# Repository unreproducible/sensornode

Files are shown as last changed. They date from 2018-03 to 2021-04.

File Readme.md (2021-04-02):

# SensorNode - Development Board

This is a board mostly intended to make a high quality environmental sensor
(BME280 or BME680) available via the magic of "IoT".  The board has some
interesting features that should make it good for training, teaching, or just
general IoT uses:
* ESP32
    * Wifi
    * Bluetooth
    * 4MB Flash
* BME280 / BME680 Support
  * Temperature
  * Pressure 
  * Humidity
* TSL2591
    * Full Spectrum Light Sensor
    * IR Spectrum Light Sensor
* MicroSD card slot
* LiPo battery support (charging and discharging)
* CP2104 USB <-> Serial Port
* Working Good Display E-ink support (specifically 2.13in screens)
    * v1.2 or later

# Getting Started
The following link is a presentation that was done in 2018 specifically targetting this board

https://events.linuxfoundation.org/wp-content/uploads/2017/12/osseu18_-_discovering_tiny_snakes_John-Hawley.pdf

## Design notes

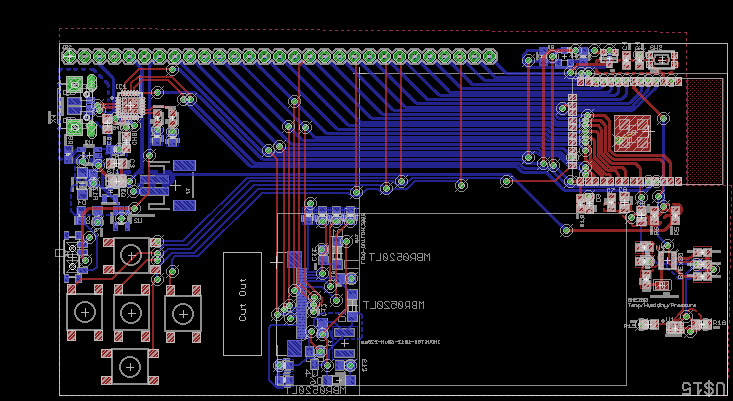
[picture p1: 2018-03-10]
Board Image - sensornode.png

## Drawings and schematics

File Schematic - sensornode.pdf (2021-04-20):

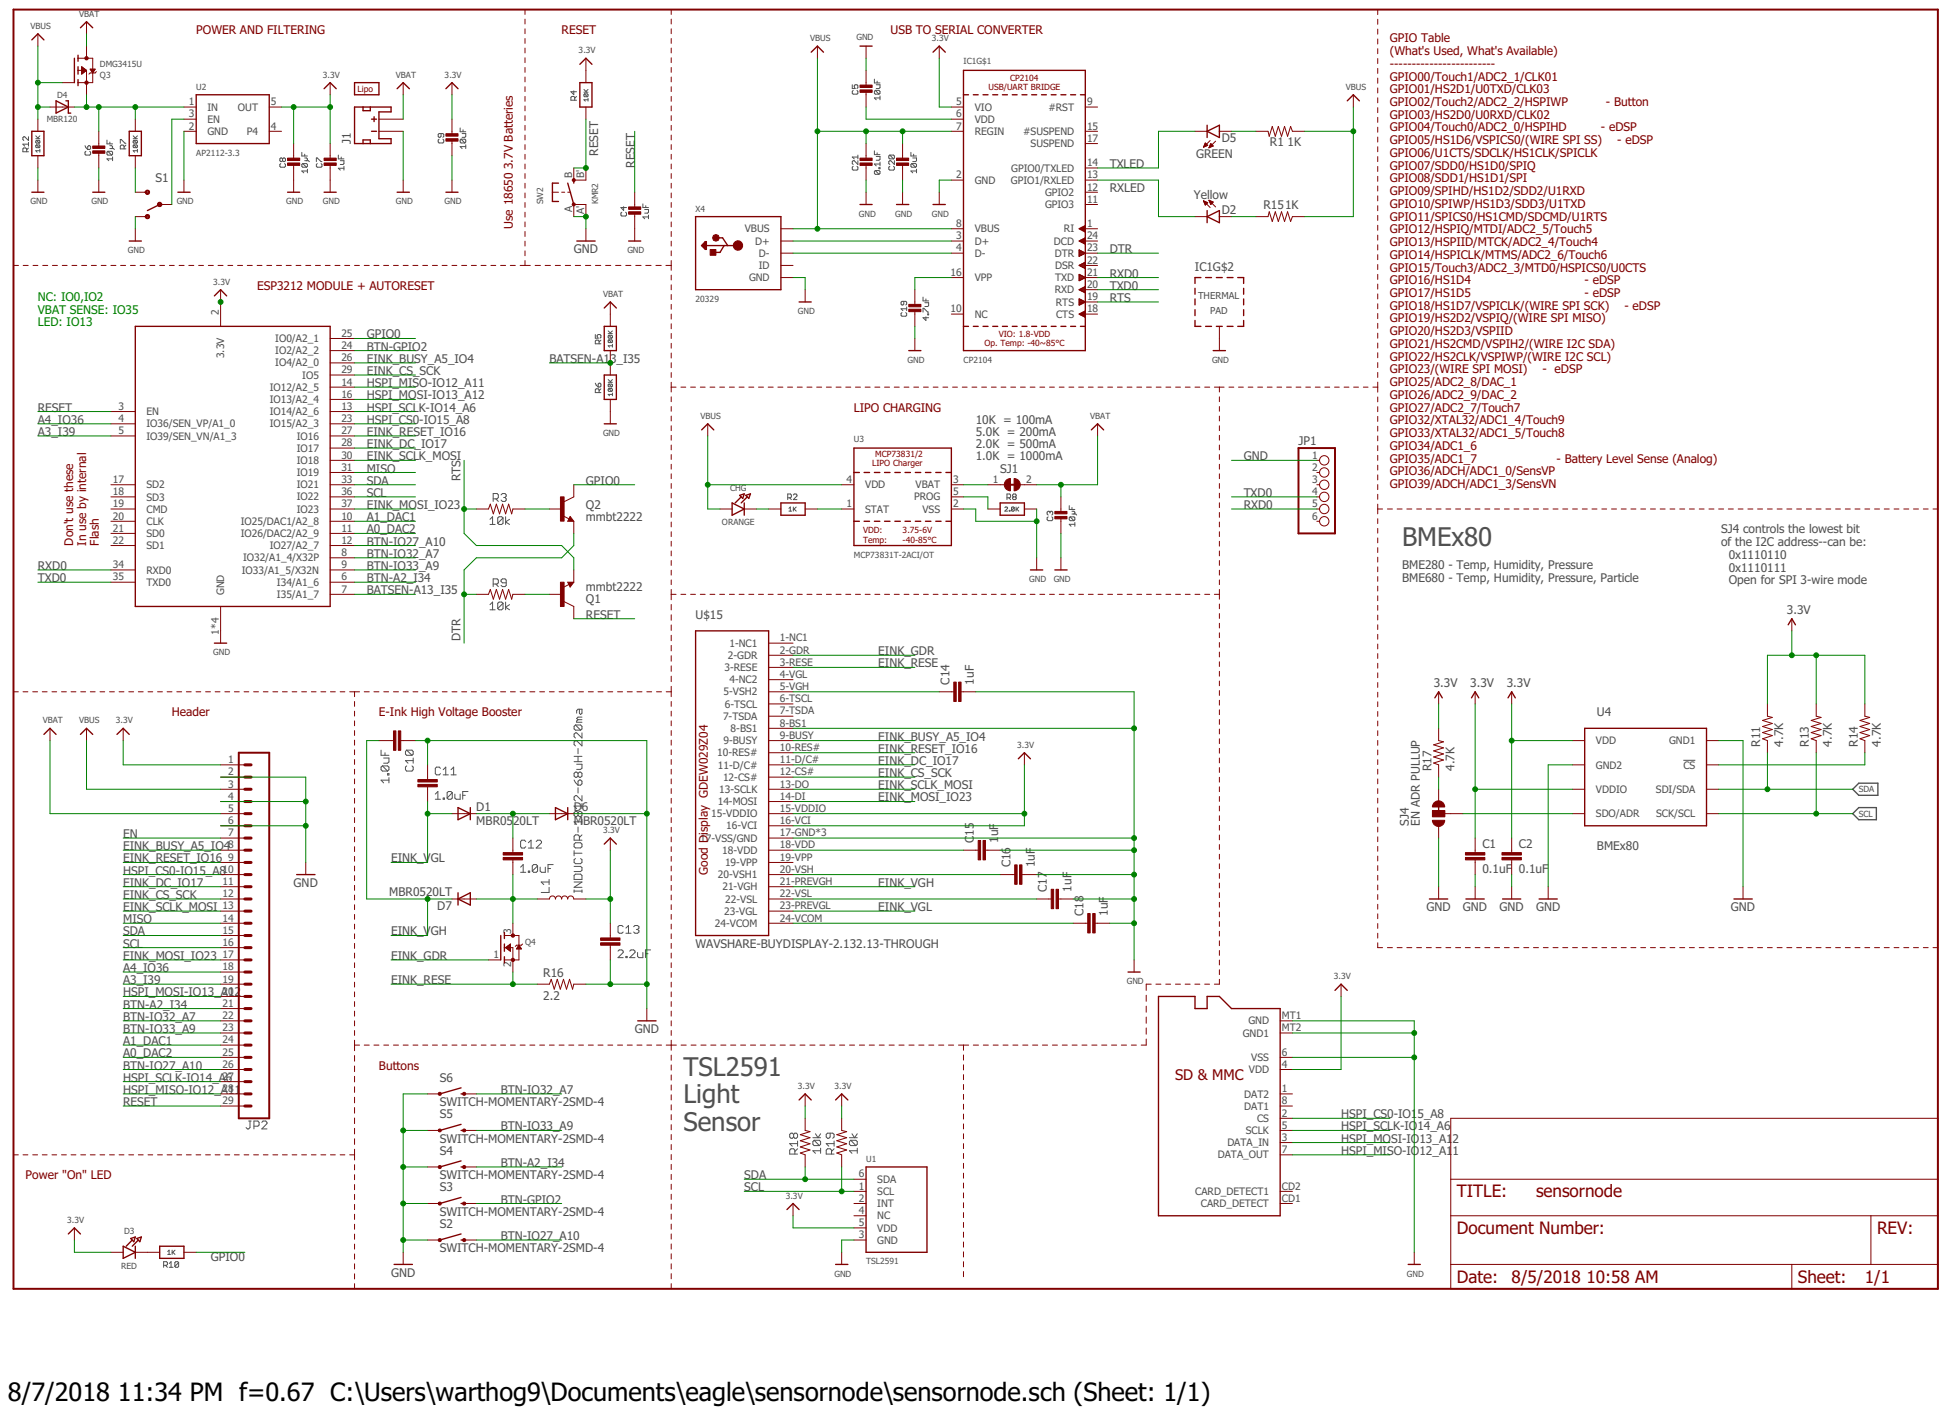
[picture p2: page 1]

GPIO Table
(What's Used, What's Available)

VIO: 1.8-VDD Op. Temp: -40~85°C

In use by internal Flash

SJ4 controls the lowest bit of the I2C address--can be: 0x1110110

0x1110111 Open for SPI 3-wire mode BME280 - Temp, Humidity, Pressure BME680 - Temp, Humidity, Pressure, Particle

E-Ink High Voltage Booster

SWITCH-MOMENTARY-2SMD-4 SWITCH-MOMENTARY-2SMD-4 SWITCH-MOMENTARY-2SMD-4

REV: TITLE: Document Number: sensornode

SWITCH-MOMENTARY-2SMD-4

8/7/2018 11:34 PM f=0.67 C:\Users\warthog9\Documents\eagle\sensornode\sensornode.sch (Sheet: 1/1)

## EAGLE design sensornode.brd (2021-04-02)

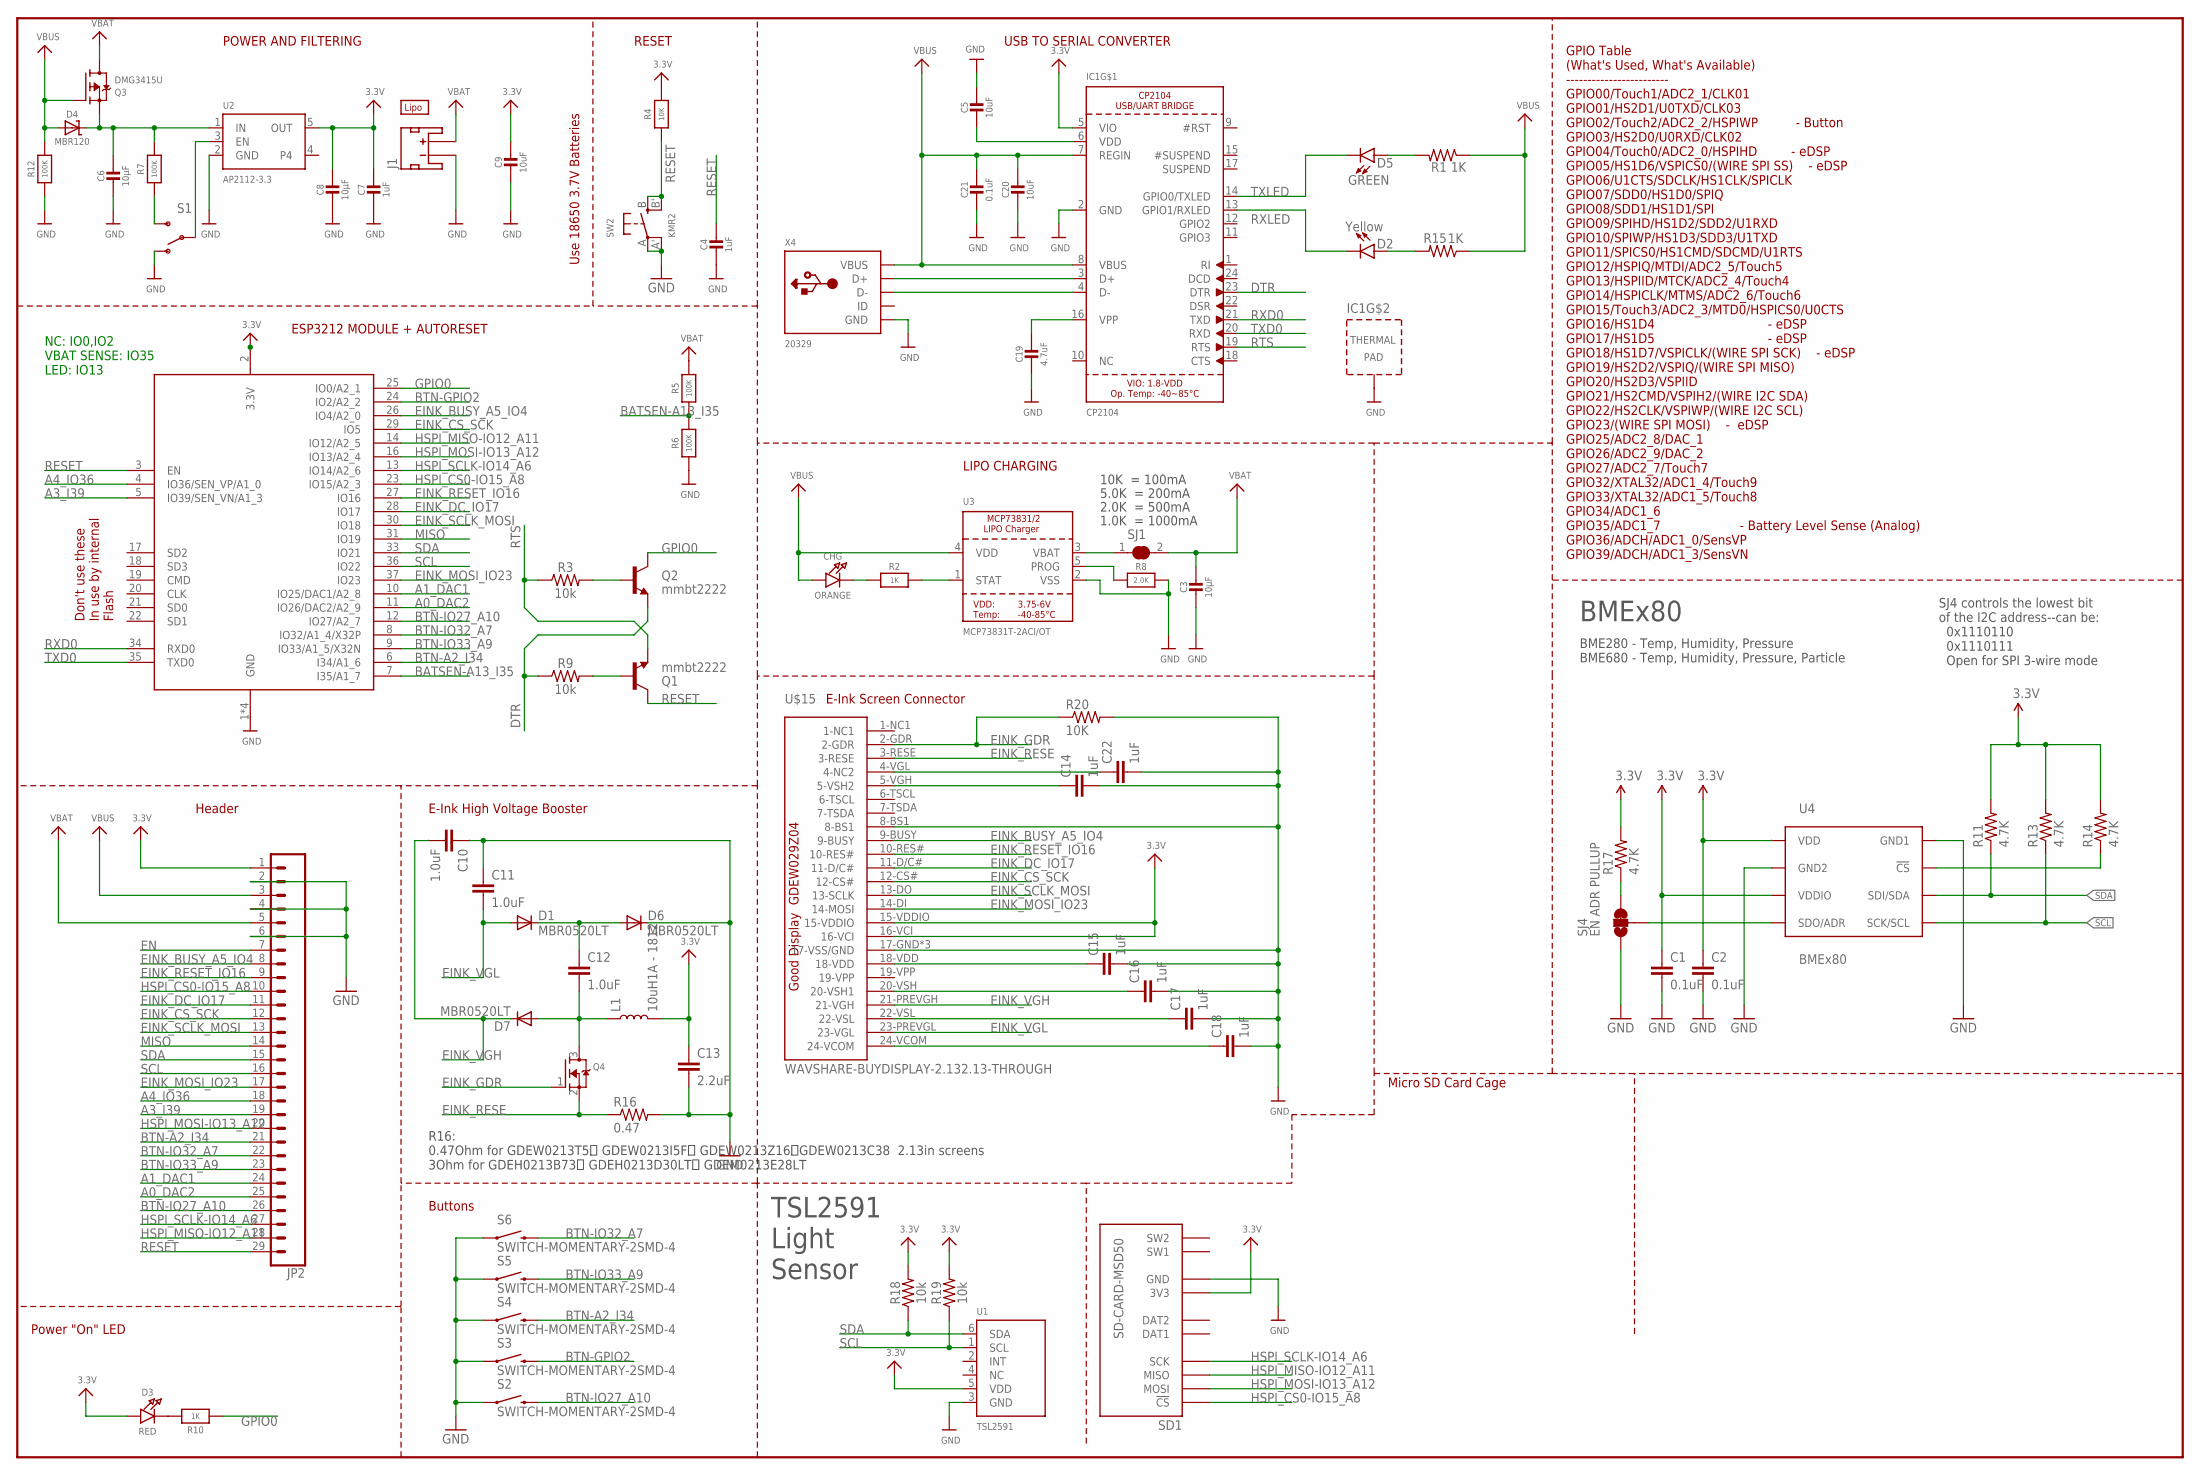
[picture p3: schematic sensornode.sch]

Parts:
BT1: LIPO-OUTLINE2000; LIPO-2000
C1, C2: 0.1uF; 0603-CAP
C3, C6, C8: 10µF; 0805-NO
C4, C7: 1uF; 0603-NO
C5, C9, C20: 10uF; 0805-NO
C10, C11, C12: 1.0uF; 0603
C13: 2.2uF; 0603
C14, C15, C16, C17, C18, C22: 1uF; 0603-CAP
C19: 4.7uF; 0805-NO
C21: 0.1uF; 0805-NO
CHG: ORANGE; CHIPLED_0805_NOOUTLINE
D1, D6, D7: MBR0520LT; SOD123
D2: Yellow; LED-0603
D3: RED; CHIPLED_0805_NOOUTLINE
D4: MBR120; SOD-123
D5: GREEN; LED-0603
IC1: CP2104; QFN24_4MM_SMSC
J1: JST_2MM_MALE; JST-2-SMD
JP2: CONN_29; 1X29
L1: 10uH1A - 1812; 1815
Q1, Q2: mmbt2222; SOT23-3
Q3: DMG3415U; SOT23-R
Q4: MOSFET-NREFLOW; SOT23
R1, R15: 1K; 0603-RES
R2, R10: 1K; 0603-NO
R3, R9, R18, R19: 10k; 0603
R4: 10K; 0603-NO
R5, R6, R7, R12: 100K; 0603-NO
R8: 2.0K; 0603-NO
R11, R13, R14, R17: 4.7K; 0603-RES
R16: 0.47; 0603-RES
R20: 10K; 0603-RES
S1: SWITCH-SPDT-SMD-A; SWITCH-SPST-SMD-A
S2, S3, S4, S5, S6: SWITCH-MOMENTARY-2SMD-4; TACTILE_SWITCH_TALL
SD1: SD-CARD-MSD50; SD_5031821853
SJ1: SOLDERJUMPER_CLOSED; SOLDERJUMPER_CLOSEDWIRE@1
SJ4: EN ADR PULLUP; PAD-JUMPER-3-2OF3_NC_BY_TRACE_YES_SILK_FULL_BOX
SW2: KMR2; BTN_KMR2_4.6X2.8
U1: TSL2591; DFN6_TAOS
U2: AP2112-3.3; SOT23-5
U3: MCP73831T-2ACI/OT; SOT23-5
U4: BMEx80; BME280_LGA
U$15: WAVSHARE-BUYDISPLAY-2.132.13-THROUGH; WAVSHARE-BUYDISPLAY-2.13-THM
X2: ESP32_WROOM32_SKINNY; WROOM32_SKINNY
X4: 20329; MICRO-USB5+6P-SMD-0.65-B

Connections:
3.3V: C1.1, C2.1, C7.1, C8.1, C9.1, C13.1, D3.A, IC1.5 (VIO), JP2.1, L1.2, R1.1, R4.2, R11.2, R13.2, R14.2, R15.1, R17.2, R18.2, R19.2, SD1.VCC (3V3), U1.5 (VDD), U2.5 (OUT), U4.P$6 (VDDIO), U4.P$8 (VDD), U$15.15-VDDIO, U$15.16-VCI, X2.2 (3.3V)
!CS: R14.1, U4.P$2 (!CS)
A0_DAC2: JP2.25, X2.11 (IO26/DAC2/A2_9)
A1_DAC1: JP2.24, X2.10 (IO25/DAC1/A2_8)
A3_I39: JP2.19, X2.5 (IO39/SEN_VN/A1_3)
A4_IO36: JP2.18, X2.4 (IO36/SEN_VP/A1_0)
BATSEN-A13_I35: R5.1, R6.2, X2.7 (I35/A1_7)
BTN-A2_I34: JP2.21, S4.B2 (2), X2.6 (I34/A1_6)
BTN-GPIO2: S3.B2 (2), X2.24 (IO2/A2_2)
BTN-IO27_A10: JP2.26, S2.B2 (2), X2.12 (IO27/A2_7)
BTN-IO32_A7: JP2.22, S6.B2 (2), X2.8 (IO32/A1_4/X32P)
BTN-IO33_A9: JP2.23, S5.B2 (2), X2.9 (IO33/A1_5/X32N)
DTR: IC1.23 (DTR), Q2.2 (E), R9.1
EINK_BUSY_A5_IO4: JP2.8, U$15.9-BUSY, X2.26 (IO4/A2_0)
EINK_CS_SCK: JP2.12, U$15.12-CS#, X2.29 (IO5)
EINK_DC_IO17: JP2.11, U$15.11-D/C#, X2.28 (IO17)
EINK_GDR: Q4.1 (G), R20.1, U$15.2-GDR
EINK_MOSI_IO23: JP2.17, U$15.14-DI (14-MOSI), X2.37 (IO23)
EINK_RESE: Q4.2 (S), R16.1, U$15.3-RESE
EINK_RESET_IO16: JP2.9, U$15.10-RES#, X2.27 (IO16)
EINK_SCLK_MOSI: JP2.13, U$15.13-DO (13-SCLK), X2.30 (IO18)
EINK_VGH: C10.2, D7.C, U$15.21-PREVGH (21-VGH)
EINK_VGL: C11.2, D1.A, U$15.23-PREVGL (23-VGL)
EN: JP2.7, S1.2, U2.3 (EN)
GND: C1.2, C2.2, C3.2, C4.2, C5.1, C6.2, C7.2, C8.2, C9.2, C10.1, C11.1, C13.2, C14.2, C15.2, C16.2, C17.2, C18.2, C19.2, C20.2, C21.2, C22.2, D6.C, IC1.2 (GND), IC1.THERM (TP), J1.1 (-), JP2.2, JP2.4, JP2.6, R6.1, R8.2, R12.1, R16.2, R20.2, S1.1 (O), S2.A2 (1), S3.A2 (1), S4.A2 (1), S5.A2 (1), S6.A2 (1), SD1.GND, SJ4.1, SW2.A, SW2.A' (P1), U1.3 (GND), U2.2 (GND), U3.2 (VSS), U4.P$1 (GND1), U4.P$7 (GND2), U$15.8-BS1, U$15.17-GND (17-VSS/GND), U$15.25 (17-VSS/GND), U$15.26 (17-VSS/GND), X2.1 (GND), X2.15 (GND), X2.38 (GND), X2.P$1 (GND), X4.5 (GND), X4.S1 (GND), X4.S2 (GND), X4.S3 (GND), X4.S4 (GND), X4.S5 (GND), X4.S6 (GND)
GPIO0: Q2.3 (C), R10.1, X2.25 (IO0/A2_1)
HSPI_CS0-IO15_A8: JP2.10, SD1.CS (!CS), X2.23 (IO15/A2_3)
HSPI_MISO-IO12_A11: JP2.28, SD1.MISO, X2.14 (IO12/A2_5)
HSPI_MOSI-IO13_A12: JP2.20, SD1.MOSI, X2.16 (IO13/A2_4)
HSPI_SCLK-IO14_A6: JP2.27, SD1.SCK, X2.13 (IO14/A2_6)
MISO: JP2.14, X2.31 (IO19)
unnamed: CHG.C, R2.1
unnamed: R8.1, U3.5 (PROG)
unnamed: R2.2, U3.1 (STAT)
unnamed: R7.1, S1.3 (S)
unnamed: D3.C, R10.2
unnamed: C5.2, IC1.6 (VDD)
unnamed: C6.1, D4.C, Q3.2 (S), R7.2, U2.1 (IN)
unnamed: D5.A, R1.2
unnamed: SJ1.1, U3.3 (VBAT)
unnamed: D2.A, R15.2
unnamed: C12.1, D1.C, D6.A
unnamed: Q1.1 (B), R9.2
unnamed: Q2.1 (B), R3.2
unnamed: C12.2, D7.A, L1.1, Q4.3 (D)
unnamed: R17.1, SJ4.3
unnamed: C15.1, U$15.18-VDD
unnamed: C16.1, U$15.20-VSH (20-VSH1)
unnamed: C17.1, U$15.22-VSL
unnamed: C18.1, U$15.24-VCOM
unnamed: C14.1, U$15.5-VGH (5-VSH2)
unnamed: C19.1, IC1.16 (VPP)
unnamed: C22.1, U$15.4-VGL (4-NC2)
RESET: C4.1, JP2.29, Q1.3 (C), R4.1, SW2.B (S), SW2.B' (S1), X2.3 (EN)
RTS: IC1.19 (RTS), Q1.2 (E), R3.1
RXD0: IC1.21 (TXD), X2.34 (RXD0)
RXLED: D2.C, IC1.13 (GPIO1/RXLED)
SCL: JP2.16, R13.1, R19.1, U1.1 (SCL), U4.P$4 (SCK/SCL), X2.36 (IO22)
SDA: JP2.15, R11.1, R18.1, U1.6 (SDA), U4.P$3 (SDI/SDA), X2.33 (IO21)
SDO/ADR: SJ4.2, U4.P$5 (SDO/ADR)
TXD0: IC1.20 (RXD), X2.35 (TXD0)
TXLED: D5.C, IC1.14 (GPIO0/TXLED)
USBD_N: IC1.4 (D-), X4.2 (D-)
USBD_P: IC1.3 (D+), X4.3 (D+)
VBAT: C3.1, J1.2 (+), JP2.5, Q3.3 (D), R5.2, SJ1.2
VBUS: C20.1, C21.1, CHG.A, D4.A, IC1.7 (REGIN), IC1.8 (VBUS), JP2.3, Q3.1 (G), R12.2, U3.4 (VDD), X4.1 (VBUS)

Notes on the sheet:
POWER AND FILTERING
RESET
10K = 100mA
5.0K = 200mA
2.0K = 500mA
1.0K = 1000mA
USB TO SERIAL CONVERTER
LIPO CHARGING
Power "On" LED
GPIO Table (What's Used, What's Available) ------------------------ GPIO00/Touch1/ADC2_1/CLK01 GPIO01/HS2D1/U0TXD/CLK03 GPIO02/Touch2/ADC2_2/HSPIWP - Button GPIO03/HS2D0/U0RXD/CLK02 GPIO04/Touch0/ADC2_0/HSPIHD - eDSP GPIO05/HS1D6/VSPICS0/(WIRE SPI SS) - eDSP GPIO06/U1CTS/SDCLK/HS1CLK/SPICLK GPIO07/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
Header
Buttons
Use 18650 3.7V Batteries
ESP3212 MODULE + AUTORESET
NC: IO0,IO2 VBAT SENSE: IO35 LED: IO13
Don't use these In use by internal Flash
E-Ink High Voltage Booster
TSL2591 Light Sensor
BMEx80
SJ4 controls the lowest bit of the I2C address--can be: 0x1110110 0x1110111 Open for SPI 3-wire mode
BME280 - Temp, Humidity, Pressure BME680 - Temp, Humidity, Pressure, Particle
E-Ink Screen Connector
Micro SD Card Cage
R16: 0.47Ohm for GDEW0213T5、 GDEW0213I5F、 GDEW0213Z16、GDEW0213C38 2.13in screens 3Ohm for GDEH0213B73、 GDEH0213D30LT、 GDEM0213E28LT

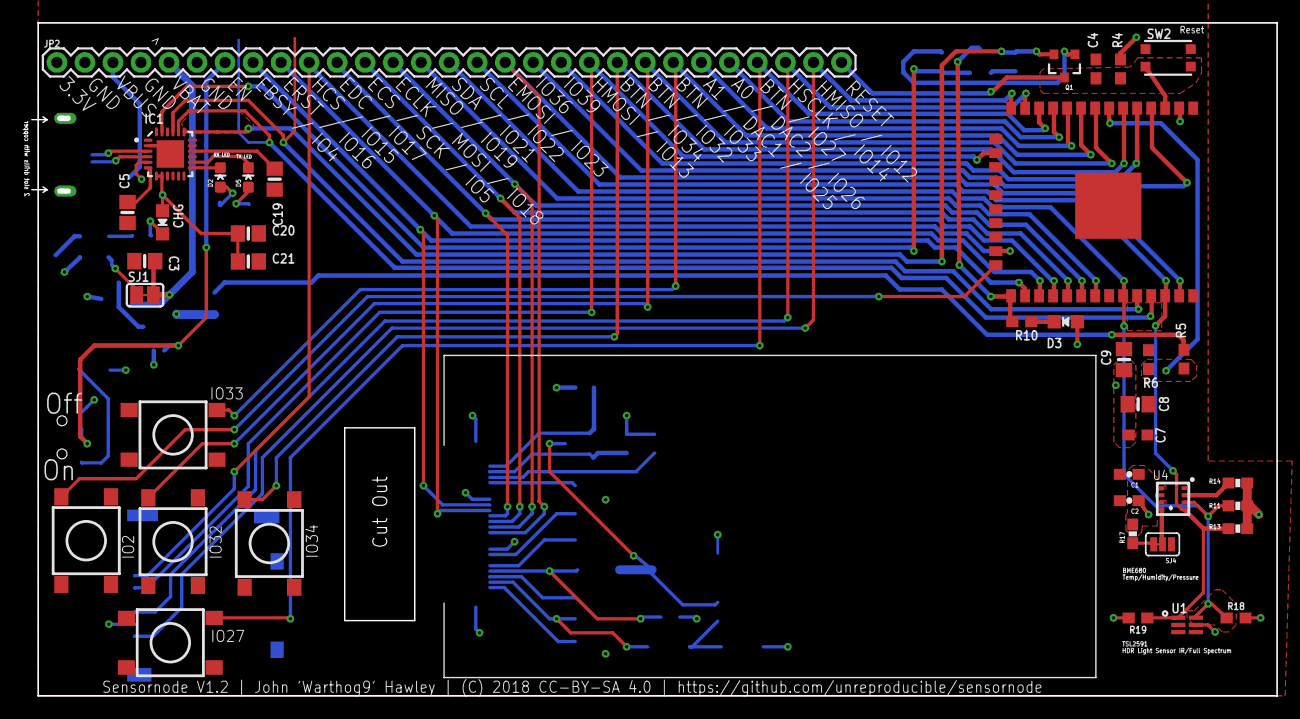
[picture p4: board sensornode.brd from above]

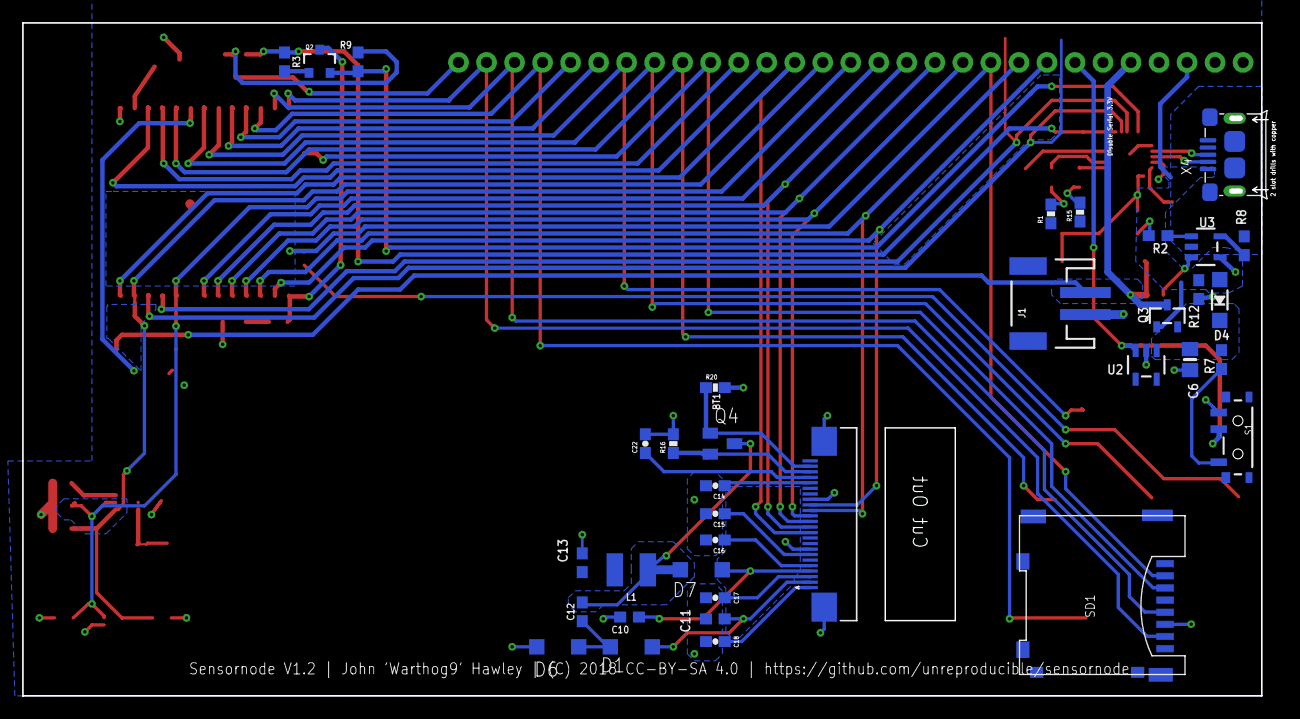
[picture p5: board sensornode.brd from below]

Board: 2 copper layers, 112.9 x 61.0 mm, 76 parts (36 on the bottom side), 66 nets.

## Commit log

2016-12-18 Adding the schematic
    [battle bunnies.sch]
2016-12-19 Updating schematic, and initial layout
    [battle bunnies.brd, battle bunnies.sch, battlebunnies outline r12 v2.dxf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]
2016-12-19 Updating with latest routing attempt
    [battle bunnies.brd, battle bunnies.sch]
2016-12-19 Fixing ear routing
    it's tighter now, but it's a lot better for obvious reasons
    [battle bunnies.brd]
2016-12-20 Reworking things + the ESP12S is lacking pins present on the schematic (doh)
    [battle bunnies.brd, battle bunnies.sch]
2016-12-20 Finishing up for the night, think this is all routed now
    [battle bunnies.brd]
2016-12-20 more cleanups
    [battle bunnies.brd, battle bunnies.sch]
2016-12-24 Adding in the colateral used for the silkscreen
2016-12-24 Finally moved things around enough to make it all work
    [battle bunnies.brd, battle bunnies.sch]
2016-12-25 Just adding some silk
    [battle bunnies.brd, battle bunnies.sch]
2016-12-25 more silkscreen stuff
    [battle bunnies.brd]
2016-12-27 more silk changes
    [battle bunnies.brd, battle bunnies.sch]
2017-01-07 Initial sensor board work
    [battle bunnies.brd, battle bunnies.sch, battlebunnies outline r12 v2.dxf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]
2017-06-27 Initial commit for ESP32 conversion
    [battle bunnies.brd, battle bunnies.sch]
2018-02-05 Initial, full, routing - minus Sensors, update gitignore
    [battle bunnies.brd, battle bunnies.sch]
2018-02-15 Mostly Routed - saving and pushing up
    [battle bunnies.brd, battle bunnies.sch]
2018-03-10 Big changes - 'final' routing, light sensor, bme280 -> bme680
    [battle bunnies.brd, battle bunnies.sch]
2018-03-10 Renaming the board and schematic to actually match the project
    [sensornode.brd, sensornode.sch]
2018-03-10 Cleaning up some text
    [sensornode.brd]
2018-03-10 Board: Show all layers
    [sensornode.brd]
2018-03-10 Adding board image and pdf schematic
2018-03-11 Adjusting parts based on BOM generation
    So there were a bunch of duplicated 0603 and 0805 parts, unifying
    things to 0603s
    [sensornode.brd, sensornode.sch]
2018-03-28 USB-UART: switch to "USB Powered"
    This changes the USB chip from being powered via the
    regulated 3.3V line off the board, to being powered
    via the USB VBUS power. This should basically disable
    the chip when the USB isn't plugged in.
    [sensornode.brd, sensornode.sch]
2018-04-02 BRD: updating the accepted DRC issues
    [sensornode.brd]
2018-04-05 Adjusting the keepout around the antennae
    [sensornode.brd]
2018-04-06 USB: Swapping the USB part out - twas unobtanium
    the 4UCONN connector that Adafruit used is basically made of unobtanium
    and more or less doesn't exist. The part that was trying to be used
    the rear prongs did not match up by any stretch of the imagination.
    A mess of e-mails an annoyance ensued.
    I'm swapping out the part on everything I can now, this seems to be
    more common, and there's parts that are similar enough to it that
    replacing it won't be a big deal. New part is the
    Amphenol FCI 10118193-0001LF
    [sensornode.brd, sensornode.sch]
2018-04-25 Moving sensors down-making room for wifi keep out
    [sensornode.brd]
2018-04-25 Clearing some space around the eink screen
    [sensornode.brd]
2018-04-25 increase board height to 61mm
    Also adjust some parts near the top
    [sensornode.brd]
2018-04-25 Adjusting board width
    [sensornode.brd]
2018-05-06 Getting the updates in
    Yes, this is a terrible commit
    [sensornode.brd, sensornode.sch]
2018-05-14 Adjusting some signal names
    [sensornode.brd, sensornode.sch]
2018-07-17 Adding SD Card
    [sensornode.brd, sensornode.sch]
2018-07-17 Moving vias out from under FPC connector
    [sensornode.brd]
2018-07-17 Redoing the buttons
    [sensornode.brd, sensornode.sch]
2018-07-17 Moving traces around the FPC connector
    [sensornode.brd]
2018-07-30 Updating the FPC + part for the e-ink screen
    Think I had the pinout on the FPC backwards. This should flip it
    and move a bunch of pieces around as a result
    [sensornode.brd, sensornode.sch]
2018-08-04 Adding a 10uF Cap to the CP2104
    This make it more closely resemble the known working designs.
    Getting paranoid due to when this will need to get built.
    [sensornode.brd, sensornode.sch]
2018-08-08 Cleaning up a bunch of stuff
    [sensornode.brd, sensornode.sch]
2018-08-14 Final cleanups going to prototype v2
    [sensornode.brd, sensornode.sch]
2018-08-16 Swapping out microSD cage for the Molex
    The 4UConn cage is delightlyfully cheap, but the lead times are
    dicey. At least for this run I'm going to go with the easily
    found, but more expensive, card cage, and I'll revert when
    I've got more time on a different production run.
    [sensornode.brd, sensornode.sch]
2018-10-23 Adding Image of SensorNode v1.1, top looking
2021-04-02 Adjusting e-ink screen, and reving to v1.2
    So this adds C22, a 1uF cap on VGL and R20 to EINK_GDR. These
    fall in line with what's on the waveshare and Open Hardware Summit
    badge and should be slightly more reliable than my current circuit
    [sensornode.brd, sensornode.sch]
2021-04-02 Removing the backup FTDI port
    As it turns out my luck with the power changes to the serial port
    chip worked just fine, and as a result the FTDI header is actually
    extraneous and obnoxious. Remove it, get the board a little
    smaller.
    [sensornode.brd, sensornode.sch]
2021-04-02 Modifications to fix the e-ink screen drivers
    So turns out the e-ink screen needs two fixes:
    1) The inductor pad is just straight up wrong, so I've replaced that
    1.1) I've also moved from a 68uH coil to a 10uH1A coil (matching Good
    Display's DESPI-C02 more closely)
    2) The R16 resistor should not, in fact, be 2.2Ohm, it should be 0.47Ohm
    (though I'll note 1Ohm works)
    I believe at this point this is now a garaunteed fully working circuit.
    Any additional changes would just need to replicate what the DESPI-C02
    does, but the original design on the sensornode works with if you swap
    the R16 resistor.
    [sensornode.brd, sensornode.sch]
2021-04-20 Schematic: Updating to latest version
    This updates the schematic to the latest version

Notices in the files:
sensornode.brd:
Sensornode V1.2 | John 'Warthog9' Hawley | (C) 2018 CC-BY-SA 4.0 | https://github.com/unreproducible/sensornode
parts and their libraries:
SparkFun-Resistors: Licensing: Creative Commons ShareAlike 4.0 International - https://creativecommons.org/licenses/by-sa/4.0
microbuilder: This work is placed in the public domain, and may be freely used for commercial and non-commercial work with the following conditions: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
